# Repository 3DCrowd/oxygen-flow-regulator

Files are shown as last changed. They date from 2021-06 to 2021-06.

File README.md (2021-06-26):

# Oxygen flow regulator
This is an oxygen flow limiting device as part of the Helpful Hackathon. A 3D printable oxygen metering device that would allow the care-giver to set the pressure on the bottle of oxygen and know how much oxygen they are getting. 

The concept is similar to an orifice flow metering device, where if you have an orifice that the flow moves through of a set diameter and you know what the pressure drop is across that diameter you can infer the flow rate. 

To prove the concept we started with a flow rate of 10 litres per minute and pressure drop across the orifice of 1 bar. So if the flow regulator is set to 1 bar you should get 10 liters per minute of oxygen. These variables are used in a set of equations to give an orifice diameter. 

This concept is in the testing phase after which the exact dimensions may change. 

Currently the devices have been printed in PETG on a Prusa Mini using a 0.25 mm nozzle and then using a pin vise the orifice is drilled out to 0.8 mm in diameter. 


An image showing the internal flow path of the oxygen regulator


A printed version of the most up to date the oxygen regulator

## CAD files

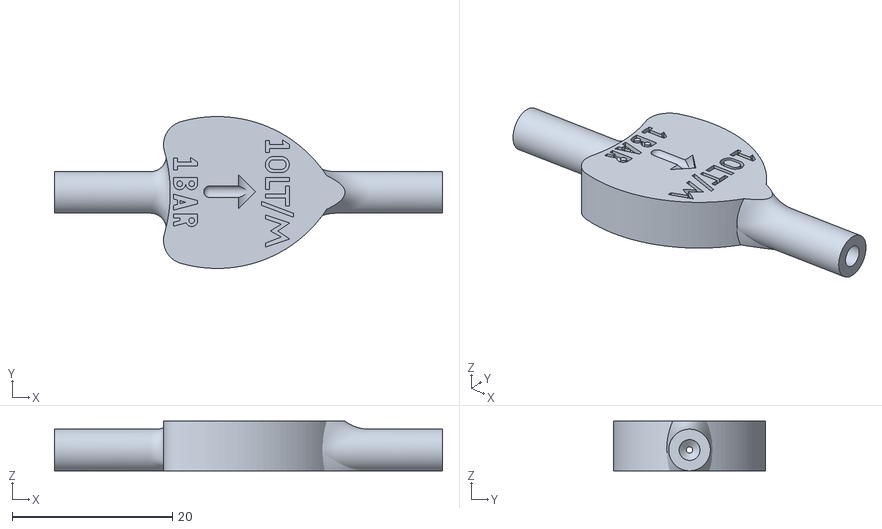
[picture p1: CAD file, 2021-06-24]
Oxygen Flow Regulator Short Aperture.stl
48.5 x 19.0 x 6.20

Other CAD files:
Oxygen Flow Regulator Short Square Aperture.stl

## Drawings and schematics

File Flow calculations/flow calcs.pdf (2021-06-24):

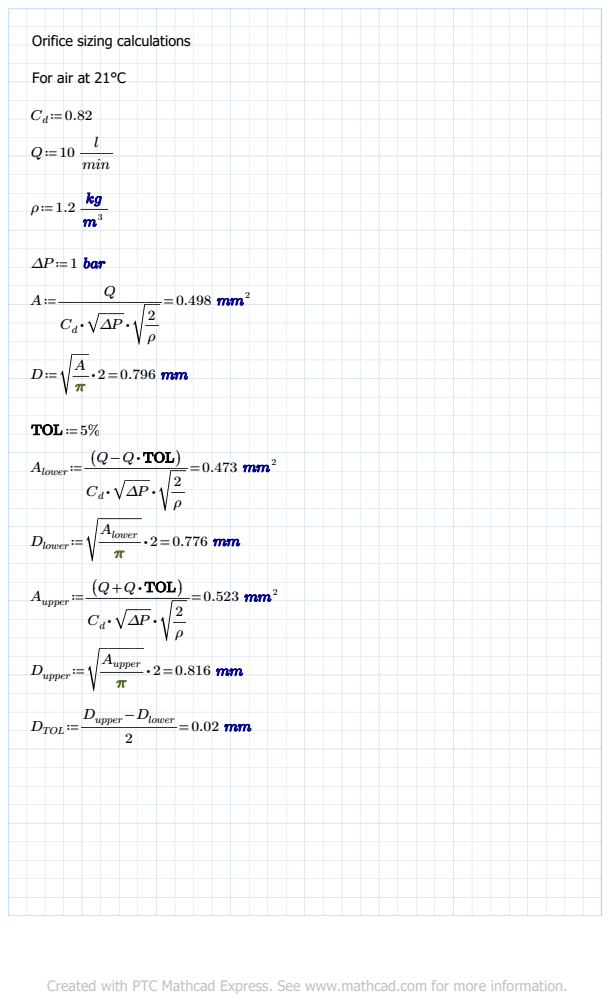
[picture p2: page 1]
Q≔10 ―l―min; ΔP≔1 bar; 0.498 mm²; TOL ≔5%; Alower≔―――――=; ((Q − Q ⋅TOL)); 0.473 mm²; Dlower≔; Alower π; Aupper≔―――――=; ((Q + Q ⋅TOL)); 0.523 mm²; Dupper≔; Aupper π; DTOL≔―――――=; Dupper− Dlower 2

Orifice sizing calculations

For air at 21°C

Created with PTC Mathcad Express. See www.mathcad.com for more information.

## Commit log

2021-06-24 Initial upload
    Initial upload of flow calculations and the initial design.
    [Oxygen Flow Regulator Short Aperture.stl]
2021-06-24 Create Oxygen Flow Regulator Short Square Aperture.stl
    This uses a square cross section aperture to hopefully improve the printability of the component.
    [Oxygen Flow Regulator Short Square Aperture.stl]
2021-06-24 Update Oxygen Flow Regulator Short Aperture.stl
    We are going to attempt to print the component and then using a pin vise drill out to the required diameter. This change moves the aperture closer to the outlet of the part, allowing better access with the drill.
    [Oxygen Flow Regulator Short Aperture.stl]
